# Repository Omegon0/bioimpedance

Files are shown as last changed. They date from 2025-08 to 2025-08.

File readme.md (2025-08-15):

# Bioimpedance

An ESP32-based dev board wtih an onboard MAX30001 sensor. Designed for 4-wire ECG and respiratory monitoring. 

### What even is bioimpedance? 

Bioimpedance is a method that measures the body's resistance to flow of current. It can be used to estimate body composition but it isn't as accurate as other methods. Since it does measure changes over brief time intervals, the MAX30001 sensor can be used to track respiratory rate as well. 

### What's with this board? 

The MAX30001 IC is a 30-bump wafer-level package (WLP) so it was super difficult to fit it onto a two layer board. Reducing clearances to the minimum was necessary to route all traces. A properly functioning MAX30001 is NOT guaranteed with this project! 
How many DRC/ERC errors are there? LOTS!!! Over 100 violations that need to be fixed. This board WILL take some time to polish! However it is technically production ready. 

### Images

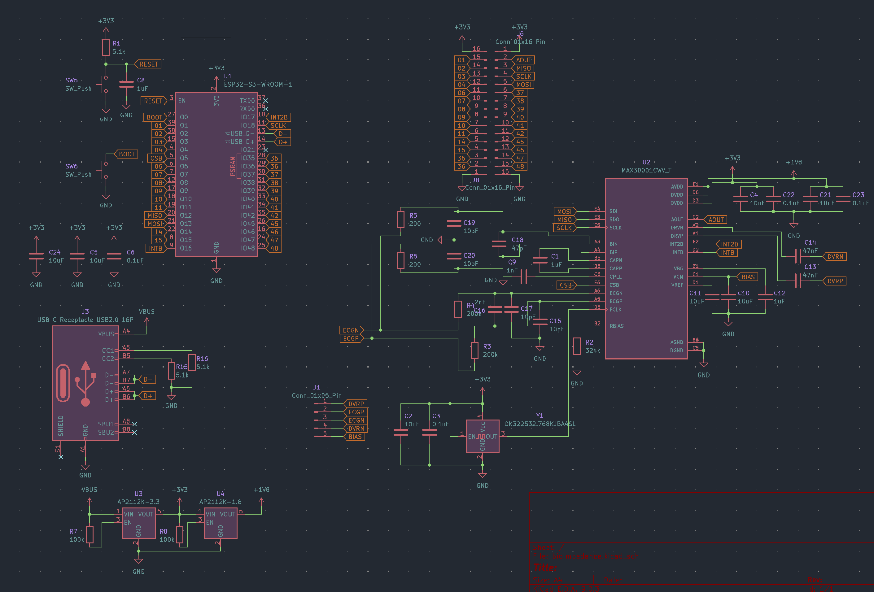
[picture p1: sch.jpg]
sch

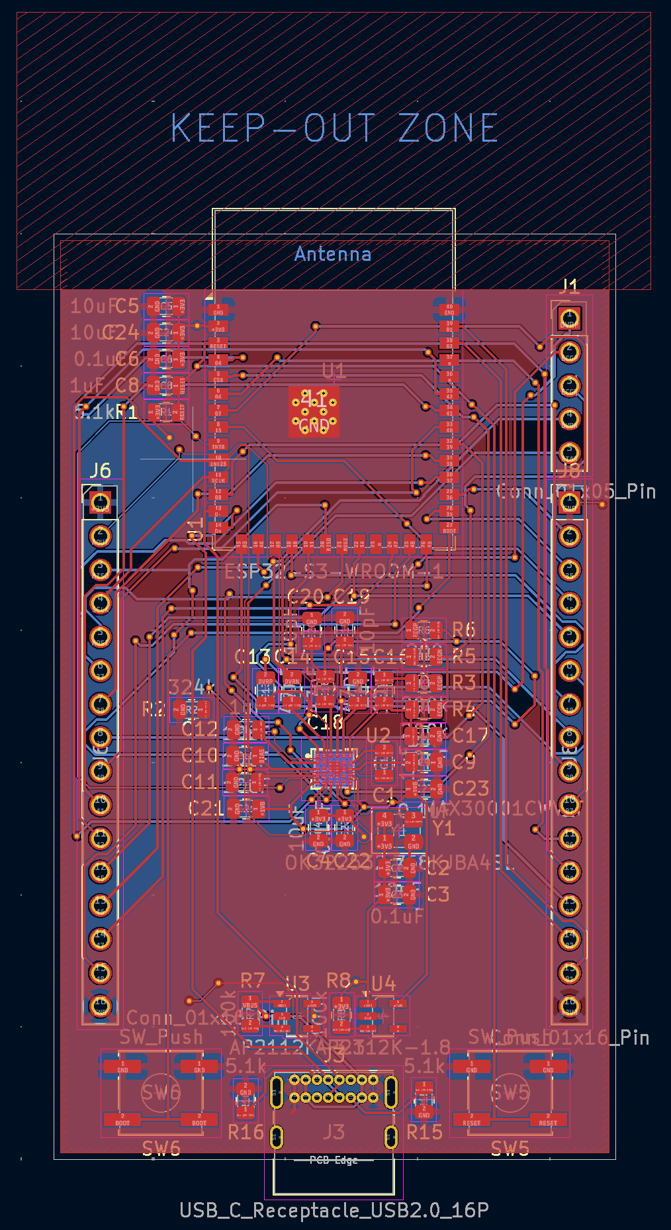
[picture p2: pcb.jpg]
pcb

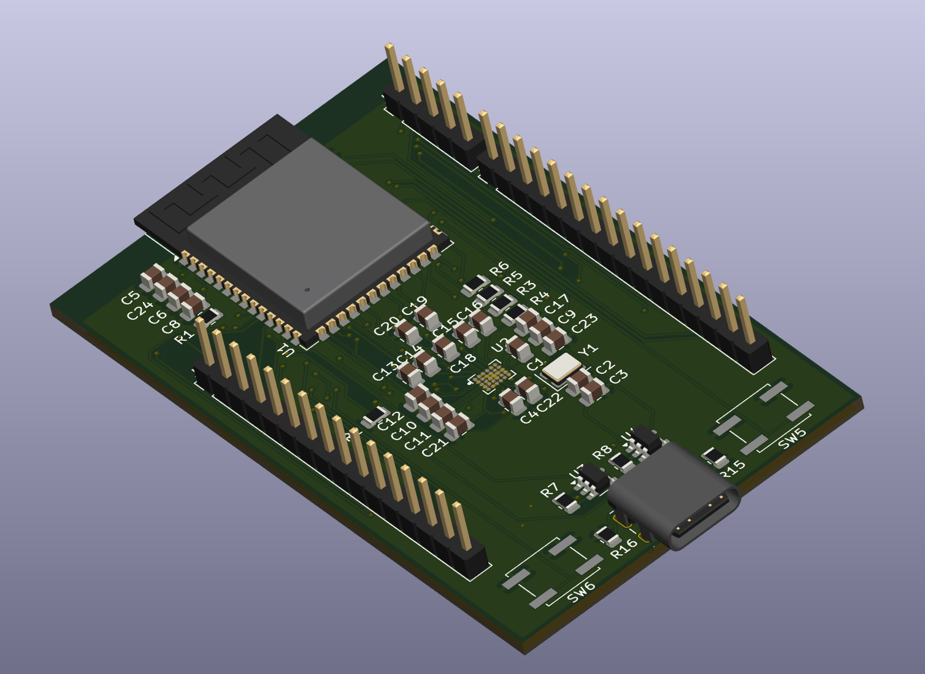
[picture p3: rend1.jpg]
rend1

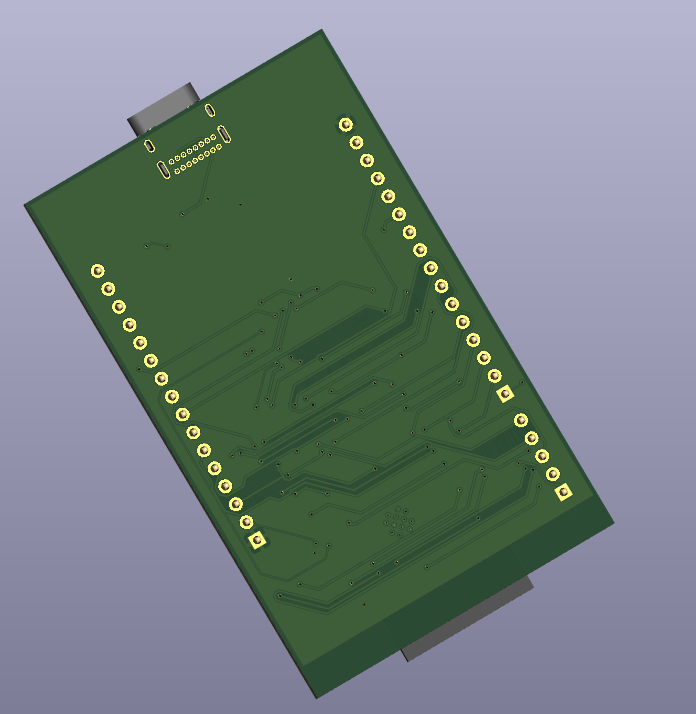
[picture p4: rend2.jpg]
rend2


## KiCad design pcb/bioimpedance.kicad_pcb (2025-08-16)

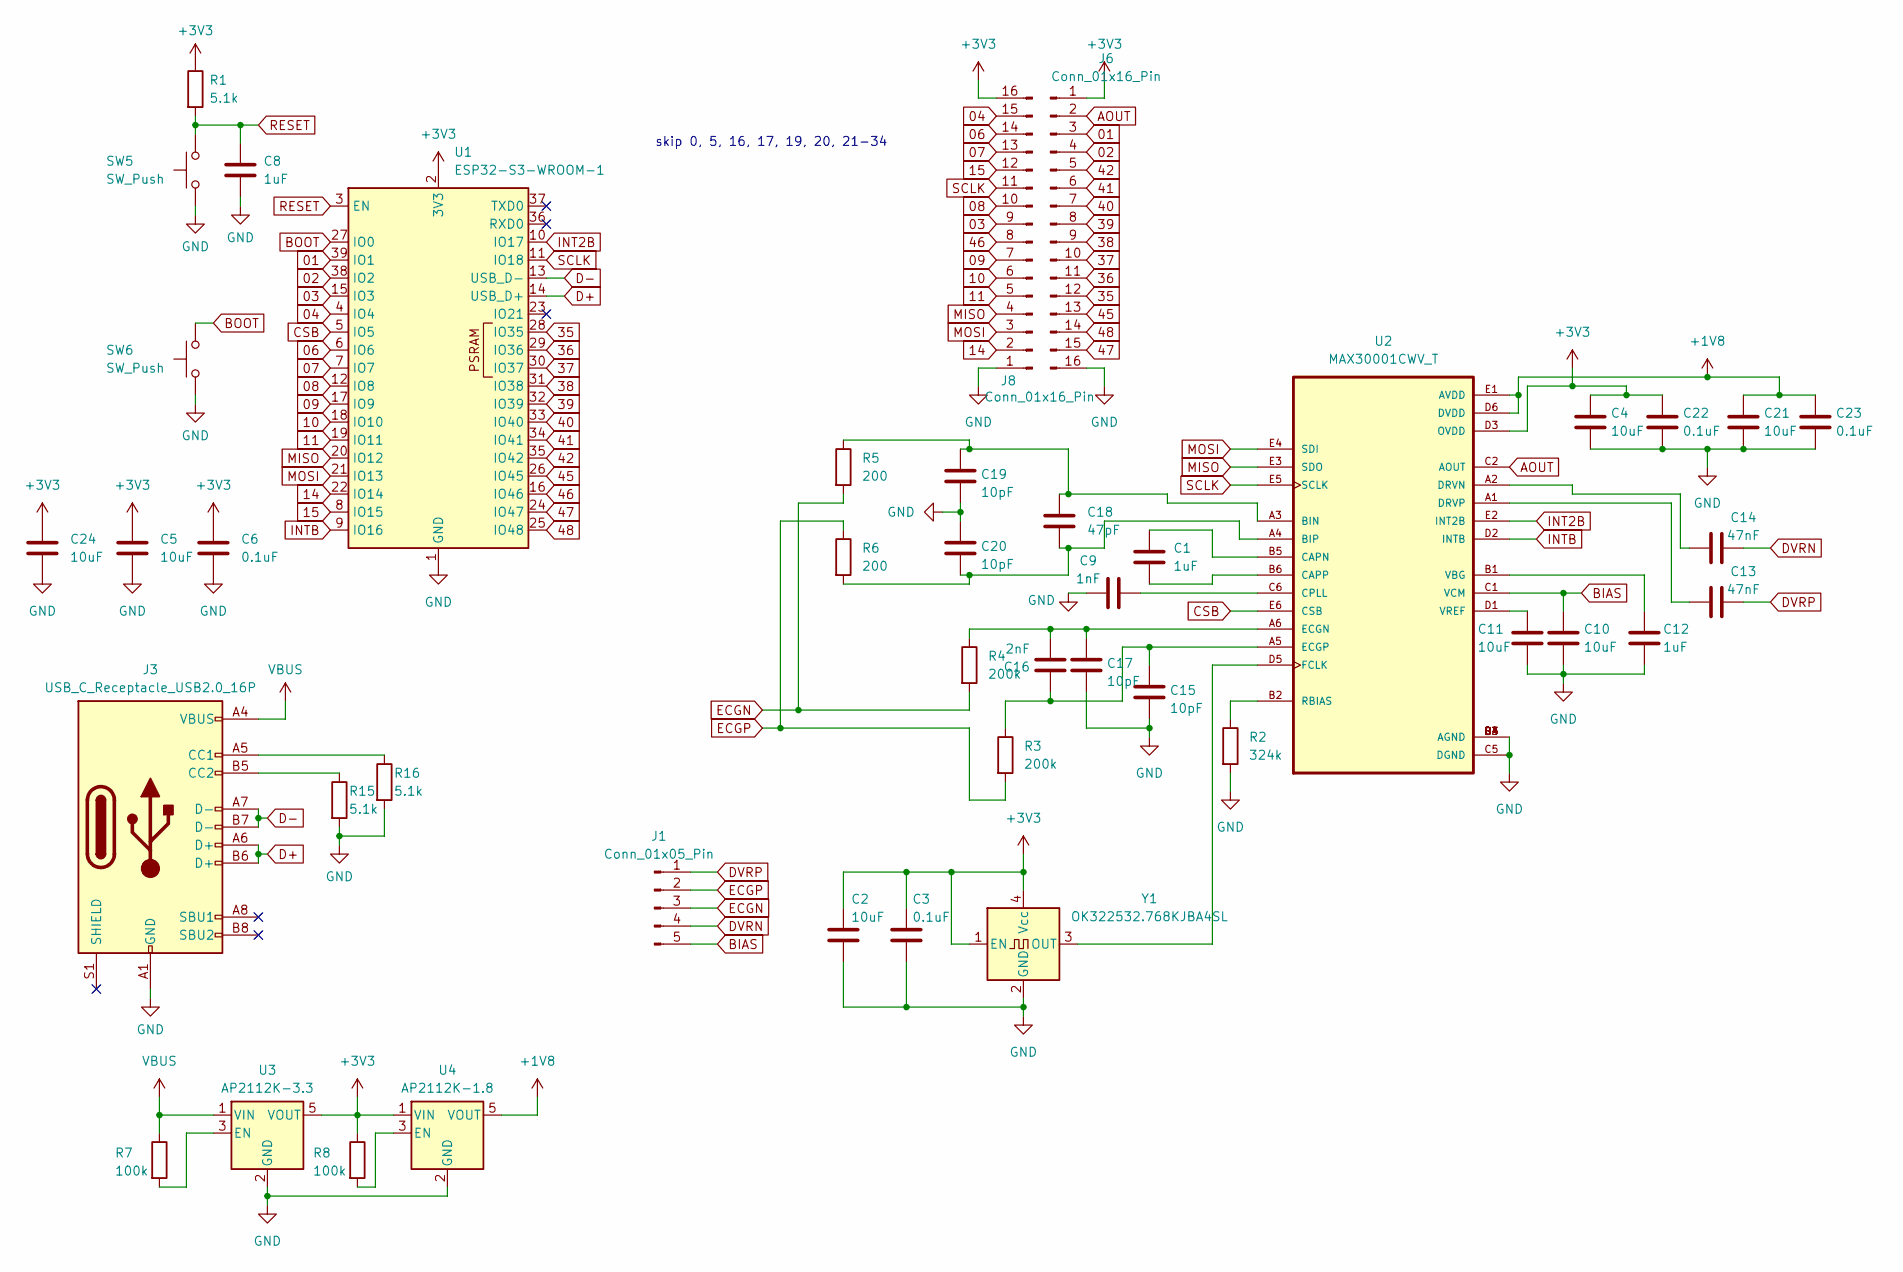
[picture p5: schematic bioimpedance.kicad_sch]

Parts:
C1, C8, C12: 1uF; C_0805_2012Metric
C2, C4, C5, C10, C11, C21, C24: 10uF; C_0805_2012Metric
C3, C6, C22, C23: 0.1uF; C_0805_2012Metric
C9: 1nF; C_0805_2012Metric
C13, C14: 47nF; C_0805_2012Metric
C15, C17, C19, C20: 10pF; C_0805_2012Metric
C16: 2nF; C_0805_2012Metric
C18: 47pF; C_0805_2012Metric
J1: Conn_01x05_Pin; PinHeader_1x05_P2.54mm_Vertical
J3: USB_C_Receptacle_USB2.0_16P; USB_C_Receptacle_GCT_USB4085
J6, J8: Conn_01x16_Pin; PinHeader_1x16_P2.54mm_Vertical
R1, R15, R16: 5.1k; R_0805_2012Metric
R2: 324k; R_0805_2012Metric
R3, R4: 200k; R_0805_2012Metric
R5, R6: 200; R_0805_2012Metric
R7, R8: 100k; R_0805_2012Metric
SW5, SW6: SW_Push; SW_Push_1P1T_NO_CK_KSC6xxJ
U1: ESP32-S3-WROOM-1
U2: MAX30001CWV_T; BGA30N50P5X6_274X292X69N
U3: AP2112K-3.3; SOT-23-5
U4: AP2112K-1.8; SOT-23-5
Y1: OK322532.768KJBA4SL; Crystal_SMD_3225-4Pin_3.2x2.5mm

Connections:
01: J6.3, U1.39 (IO1)
02: J6.4, U1.38 (IO2)
03: J8.9, U1.15 (IO3)
04: J8.15, U1.4 (IO4)
06: J8.14, U1.6 (IO6)
07: J8.13, U1.7 (IO7)
08: J8.10, U1.12 (IO8)
09: J8.7, U1.17 (IO9)
10: J8.6, U1.18 (IO10)
11: J8.5, U1.19 (IO11)
14: J8.2, U1.22 (IO14)
15: J8.12, U1.8 (IO15)
35: J6.12, U1.28 (IO35)
36: J6.11, U1.29 (IO36)
37: J6.10, U1.30 (IO37)
38: J6.9, U1.31 (IO38)
39: J6.8, U1.32 (IO39)
40: J6.7, U1.33 (IO40)
41: J6.6, U1.34 (IO41)
42: J6.5, U1.35 (IO42)
45: J6.13, U1.26 (IO45)
46: J8.8, U1.16 (IO46)
47: J6.15, U1.24 (IO47)
48: J6.14, U1.25 (IO48)
+1V8: C21.1, C23.1, U2.D6 (DVDD), U2.E1 (AVDD), U4.5 (VOUT)
+3V3: C2.1, C3.1, C4.1, C5.1, C6.1, C22.1, C24.1, J6.1, J8.16, R1.1, R8.1, U1.2 (3V3), U2.D3 (OVDD), U3.5 (VOUT), U4.1 (VIN), Y1.1 (EN), Y1.4 (Vcc)
AOUT: J6.2, U2.C2 (AOUT)
BIAS: C10.1, J1.5, U2.C1 (VCM)
BOOT: SW6.2, U1.27 (IO0)
CSB: U1.5 (IO5), U2.E6 (CSB)
D+: J3.A6 (D+), J3.B6 (D+), U1.14 (USB_D+)
D-: J3.A7 (D-), J3.B7 (D-), U1.13 (USB_D-)
DVRN: C14.2, J1.4
DVRP: C13.2, J1.1
ECGN: J1.3, R4.2, R5.2
ECGP: J1.2, R3.2, R6.1
GND: C2.2, C3.2, C4.2, C5.2, C6.2, C8.2, C9.1, C10.2, C11.2, C12.2, C15.2, C17.2, C19.2, C20.1, C21.2, C22.2, C23.2, C24.2, J3.A1 (GND), J3.A12 (GND), J3.B1 (GND), J3.B12 (GND), J6.16, J8.1, R2.2, R15.2, R16.2, SW5.1, SW6.1, U1.1 (GND), U1.40 (GND), U1.41 (GND), U2.B3 (AGND), U2.B4 (AGND), U2.C3 (AGND), U2.C4 (AGND), U2.C5 (DGND), U2.D4 (AGND), U3.2 (GND), U4.2 (GND), Y1.2 (GND)
INT2B: U1.10 (IO17), U2.E2 (INT2B)
INTB: U1.9 (IO16), U2.D2 (INTB)
MISO: J8.4, U1.20 (IO12), U2.E3 (SDO)
MOSI: J8.3, U1.21 (IO13), U2.E4 (SDI)
unnamed: J3.A5 (CC1), R16.1
unnamed: J3.B5 (CC2), R15.1
unnamed: C18.1, C19.1, R5.1, U2.A3 (BIN)
unnamed: C18.2, C20.2, R6.2, U2.A4 (BIP)
unnamed: C1.1, U2.B5 (CAPN)
unnamed: C1.2, U2.B6 (CAPP)
unnamed: C9.2, U2.C6 (CPLL)
unnamed: C14.1, U2.A2 (DRVN)
unnamed: C13.1, U2.A1 (DRVP)
unnamed: C16.2, C17.1, R4.1, U2.A6 (ECGN)
unnamed: C15.1, C16.1, R3.1, U2.A5 (ECGP)
unnamed: U2.D5 (FCLK), Y1.3 (OUT)
unnamed: R2.1, U2.B2 (RBIAS)
unnamed: C12.1, U2.B1 (VBG)
unnamed: C11.1, U2.D1 (VREF)
unnamed: R7.2, U3.3 (EN)
unnamed: R8.2, U4.3 (EN)
RESET: C8.1, R1.2, SW5.2, U1.3 (EN)
SCLK: J8.11, U1.11 (IO18), U2.E5 (SCLK)
VBUS: J3.A4 (VBUS), J3.A9 (VBUS), J3.B4 (VBUS), J3.B9 (VBUS), R7.1, U3.1 (VIN)

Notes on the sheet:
skip 0, 5, 16, 17, 19, 20, 21-34

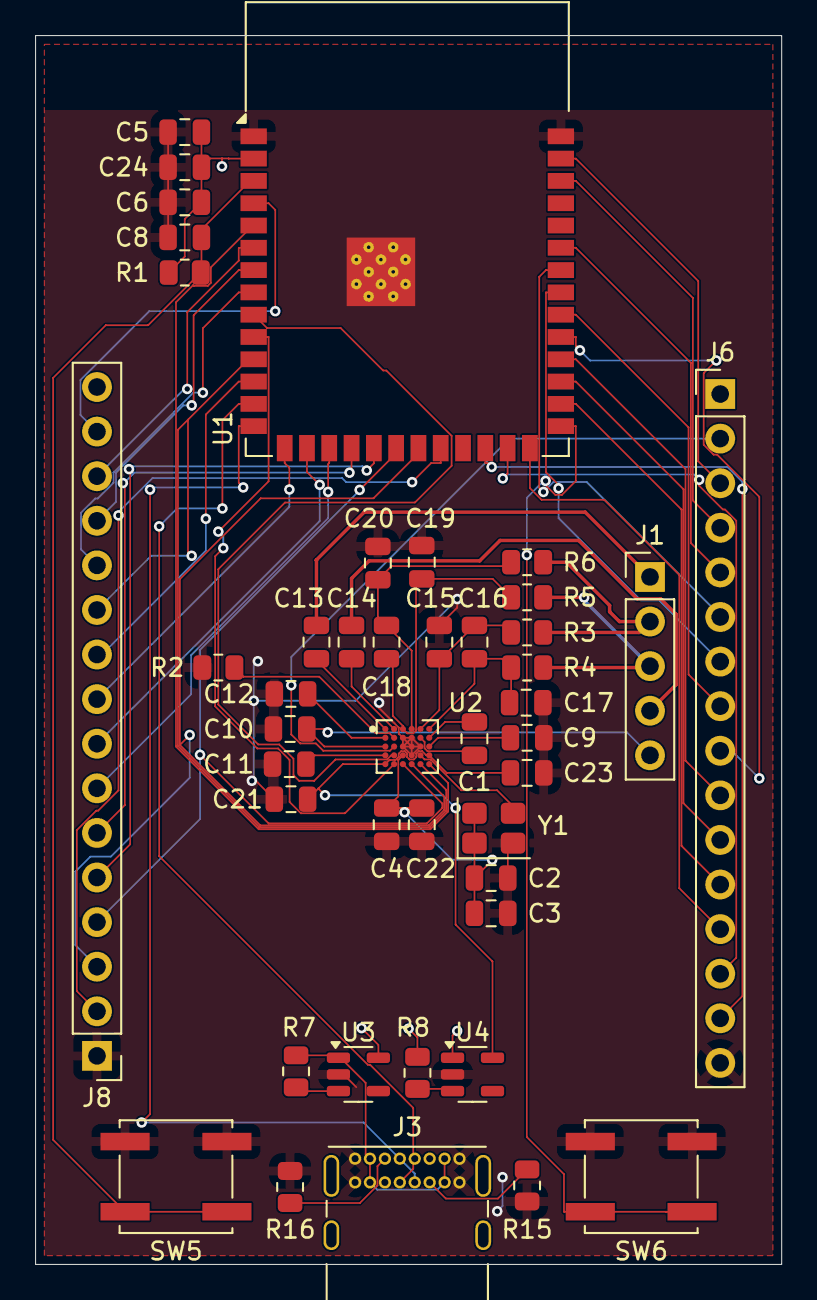
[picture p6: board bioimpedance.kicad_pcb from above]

Board: 2 copper layers, 42.5 x 70.0 mm, 44 parts (0 on the bottom side), 61 nets.

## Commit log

2025-08-15 Added readme, images, and PCB
    [bioimpedance.kicad_pcb, bioimpedance.kicad_sch, freerouting.dsn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]
2025-08-15 reroute pcb
    [bioimpedance.kicad_pcb, bioimpedance.kicad_sch, freerouting.dsn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]
